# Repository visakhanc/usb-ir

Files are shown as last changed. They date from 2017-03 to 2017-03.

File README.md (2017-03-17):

USB-IR - IR receiver based on V-USB
===================================

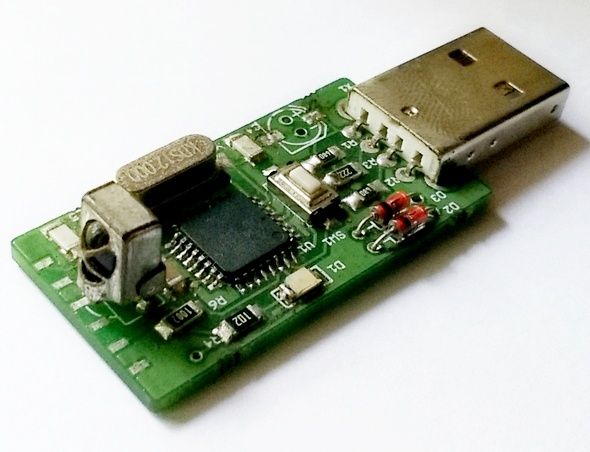
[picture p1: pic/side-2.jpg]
HID IR Remote


USB-IR is an infrared remote control receiver with a USB communication enabled by v-usb usb stack. So, it can be programmed as an IR receiver for PC with specific functions assigned to various keys of a remote control.

HID Bootloader option
---------------------

Firmware updates can be done through USB itself! For this, HID bootloader should be initially flashed into the AVR through ISP pins. After this, to program firmware using bootloader, just plug in the USB while pressing and holding the button. It will get detected as 'HIDBoot' device. Now use the command line tool for HID bootloader to program hex files. like this:
bootloadHID.exe -r main.hex

Find the HID bootloader here: [HID bootloader](https://github.com/visakhanc/vusb_projects/tree/master/bootloadHID.2012-12-08)

Examples
--------

[HID IR Remote](https://github.com/visakhanc/usb-ir/blob/master/firmware/hid-ir-remote) : Demonstrates the usage of USB-IR as a multimedia remote control receiver for PC. Sony IR protocol (SIRC) is used here. Implemented functions are: Volume Up/Down, Next, Previous, Pause, Play, Stop, Mute.

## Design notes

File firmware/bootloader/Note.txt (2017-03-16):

This is HID bootloader modified for the USB-IR hardware with PORTD:1 as boot pin
XTAL: 12 MHz (chage in makefile)
Bootloader switch: PORTD:1 (change in bootloader_config.h)

STEPS:

1. make fuse
2. make flash
3. make lock (optional)

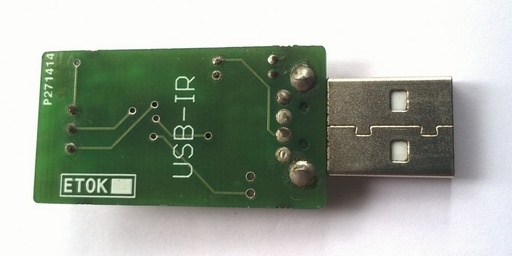
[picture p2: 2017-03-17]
pic/bottom-1.jpg

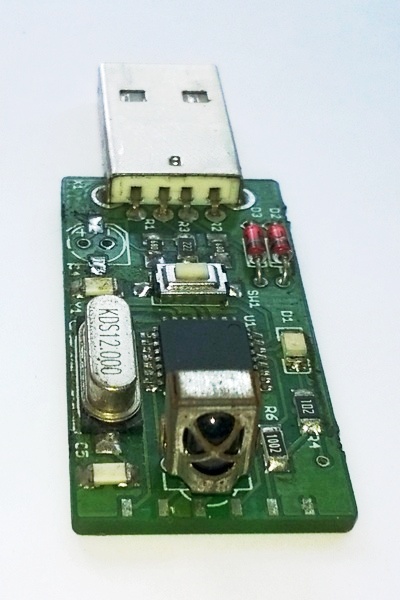
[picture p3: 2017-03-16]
pic/side-1.jpg

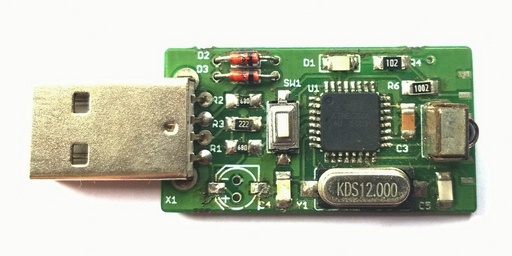
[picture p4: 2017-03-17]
pic/top-1.jpg

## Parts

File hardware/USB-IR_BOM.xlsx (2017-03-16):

Qty | Value | Device | Package | Parts | Description | Price
1 | 100n | CAP1206 | 1206 | C3 | Capacitor | 0.5
1 | 10k | RESISTOR1206 | 1206 | R6 | Resistor | 0.5
1 | 12MHz | CRYSTALSMD | HC49UP | Y1 | Various standard crystals. Proven footprints. | 12
1 | 1k | RESISTOR1206 | 1206 | R4 | Resistor | 0.5
2 | 22p | CAP1206 | 1206 | C4, C5 | Capacitor | 0.5
1 | 2k2 | RESISTOR1206 | 1206 | R3 | Resistor | 0.5
2 | 3.6V | DIODE-ZENERPTH | DIODE-ZENER | D2, D3 | Zener Diode | 2
2 | 68 | RESISTOR1206 | 1206 | R1, R2 | Resistor | 0.5
1 | CAP_POL_SMD_TH | CAP_POL_SMD_TH | CAP_SMD_TH_5X5 | C1 |  | 8
1 | MEGA8-AI | MEGA8-AI | TQFP32-08 | U1 | MICROCONTROLLER | 80
1 | RED | LED1206 | LED-1206 | D1 | LED | 2
1 | SPST_SWITCH | SPST_SWITCH | SMD_TACT_SWITCH | SW1 |  | 4
1 | USB-A-H | USB-A-H | USB-A-H | X1 | USB Connectors | 12
1 | VS1838X | VS1838X | VS1838X | U3 | VS1838 IR demodulator with supply rangeof 2.7V to 5V | 20
 |  |  |  |  | TOTAL | 146

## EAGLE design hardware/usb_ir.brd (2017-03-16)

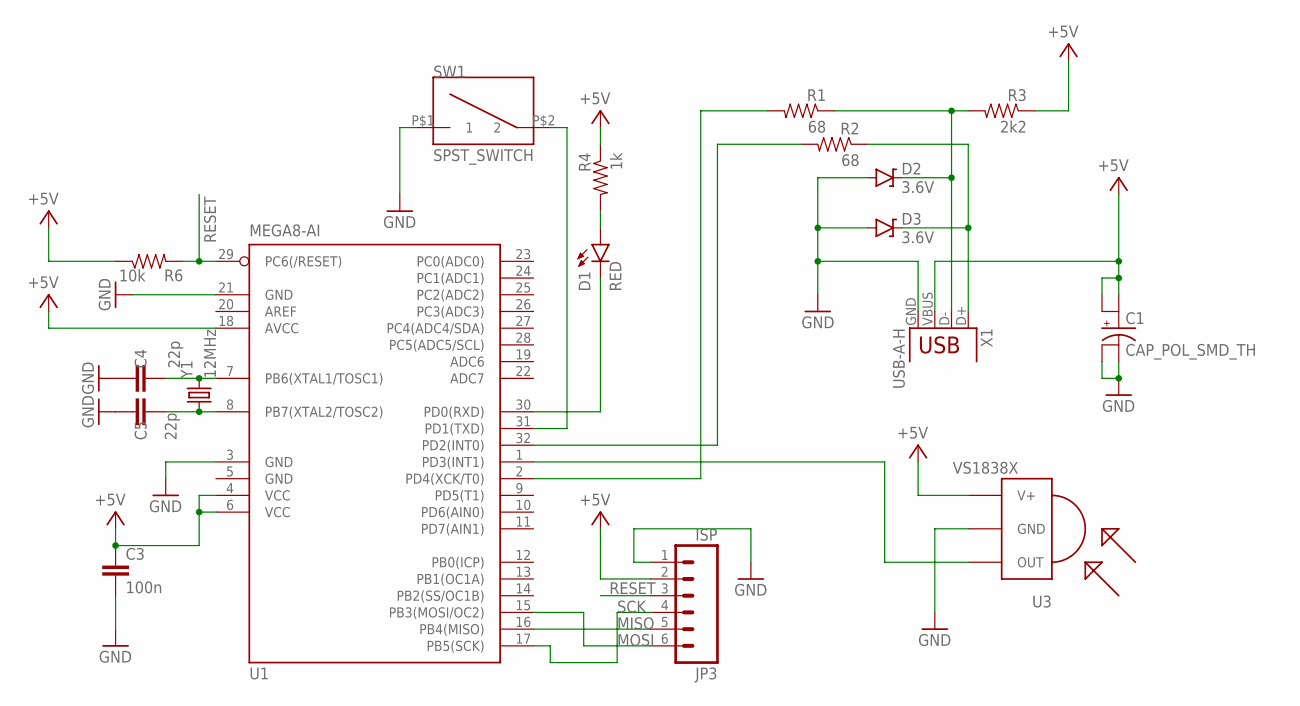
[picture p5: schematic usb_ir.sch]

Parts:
C1: CAP_POL_SMD_TH; CAP_SMD_TH_5X5
C3: 100n; 1206
C4, C5: 22p; 1206
D1: RED; LED-1206
D2, D3: 3.6V; DIODE-ZENER
JP3: ISP; 1X06-SMD_EDGE
R1, R2: 68; 1206
R3: 2k2; 1206
R4: 1k; 1206
R6: 10k; 1206
SW1: SPST_SWITCH; SMD_TACT_SWITCH
U1: MEGA8-AI; TQFP32-08
U3: VS1838X
X1: USB-A-H
Y1: 12MHz; HC49UP

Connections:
+5V: C1.+, C1.+TH (+), C3.1, JP3.2, R3.1, R4.1, R6.1, U1.4 (VCC), U1.6 (VCC), U1.18 (AVCC), U3.VCC (V+), X1.VBUS
GND: C1.-, C1.-TH (-), C3.2, C4.1, C5.1, D2.P$2 (A), D3.P$2 (A), JP3.1, SW1.P$1 (1), U1.3 (GND), U1.5 (GND), U1.21 (GND), U3.GND, X1.GND
MISO: JP3.5, U1.16 (PB4(MISO))
MOSI: JP3.6, U1.15 (PB3(MOSI/OC2))
unnamed: U1.1 (PD3(INT1)), U3.OUT
unnamed: D2.P$1 (C), R1.1, R3.2, X1.D-
unnamed: D3.P$1 (C), R2.1, X1.D+
unnamed: R2.2, U1.32 (PD2(INT0))
unnamed: R1.2, U1.2 (PD4(XCK/T0))
unnamed: D1.C, U1.30 (PD0(RXD))
unnamed: SW1.P$2 (2), U1.31 (PD1(TXD))
unnamed: D1.A, R4.2
unnamed: C4.2, U1.7 (PB6(XTAL1/TOSC1)), Y1.2
unnamed: C5.2, U1.8 (PB7(XTAL2/TOSC2)), Y1.1
RESET: JP3.3, R6.2, U1.29 (PC6(/RESET))
SCK: JP3.4, U1.17 (PB5(SCK))

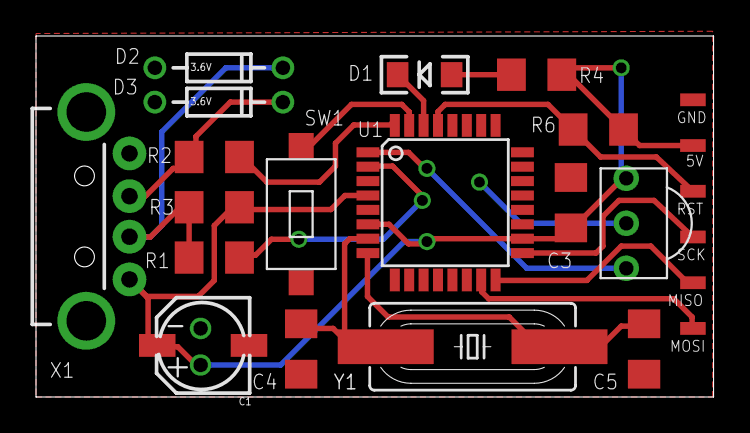
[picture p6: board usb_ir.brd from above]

Board: 2 copper layers, 37.6 x 20.1 mm, 18 parts (0 on the bottom side), 16 nets.

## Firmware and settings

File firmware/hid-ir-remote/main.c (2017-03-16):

/* Name: main.c
 * Project: hid-mouse, a very simple HID example
 * Author: Christian Starkjohann
 * Creation Date: 2008-04-07
 * Tabsize: 4
 * Copyright: (c) 2008 by OBJECTIVE DEVELOPMENT Software GmbH
 * License: GNU GPL v2 (see License.txt), GNU GPL v3 or proprietary (CommercialLicense.txt)
 */

/*
This example should run on most AVRs with only little changes. No special
hardware resources except INT0 are used. You may have to change usbconfig.h for
different I/O pins for USB. Please note that USB D+ must be the INT0 pin, or
at least be connected to INT0 as well.

We use VID/PID 0x046D/0xC00E which is taken from a Logitech mouse. Don't
publish any hardware using these IDs! This is for demonstration only!
*/

#include <avr/io.h>
#include <avr/wdt.h>
#include <avr/interrupt.h>  /* for sei() */
#include <util/delay.h>     /* for _delay_ms() */

#include <avr/pgmspace.h>   /* required by usbdrv.h */
#include "usbdrv.h"
#include "oddebug.h"        /* This is also an example for using debug macros */
#include "ir_sony.h"

#define RED_LED					PD0
#define RED_LED_DDR				DDRD
#define RED_LED_PORT			PORTD

#define RED_LED_OUT()			(RED_LED_DDR |= (1 << RED_LED))
#define RED_LED_OFF()			(RED_LED_PORT |= (1 << RED_LED))
#define RED_LED_ON()			(RED_LED_PORT &= ~(1 << RED_LED))
#define RED_LED_TOGGLE()		(RED_LED_PORT ^= (1 << RED_LED))

#define 	SEND_STATE_KB			1
#define 	SENT_STATE_KB			2
#define 	SEND_STATE_MM			3
#define 	SENT_STATE_MM			4
#define 	WAIT_STATE				0

/* Bits for Multimedia key mapping */
#define 	NO_KEYS				0
#define 	VOL_UP_KEY			(1 << 5)
#define 	VOL_DOWN_KEY		(1 << 6)
#define 	MUTE_KEY			(1 << 4)
#define 	STOP_KEY			(1 << 2)
#define 	PLAY_KEY			(1 << 3)
#define 	NEXT_KEY			(1 << 0)
#define 	PREV_KEY			(1 << 1)
#define 	POWER_KEY			(1 << 7)

/* Standard Keyboard usage codes */
#define 	KEYBOARD_RIGHT		0x4F
#define 	KEYBOARD_LEFT		0x50
#define 	KEYBOARD_UP			0x52
#define 	KEYBOARD_DOWN		0x51
#define 	KEYBOARD_F4			0x3D
#define 	KEYBOARD_ENTER		0x58
#define 	KEYBOARD_TAB		0x2B
#define 	KEYBOARD_APP		0x65
#define 	KEYBOARD_ESC		0x29
#define 	KEYBOARD_POWER		0x66

#define 	KEYBOARD_MOD_ALT	(1 << 2)
#define 	KEYBOARD_MOD_CTRL	(1 << 0)
#define 	KEYBOARD_MOD_SHIFT	(1 << 1)
#define 	KEYBOARD_MOD_GUI	(1 << 3)

/* ------------------------------------------------------------------------- */
/* ----------------------------- USB interface ----------------------------- */
/* ------------------------------------------------------------------------- */

/* Keyboard report descriptor*/
PROGMEM const char usbHidReportDescriptor[104] = { /* USB report descriptor, size must match usbconfig.h */
	
	0x05, 0x01,						// USAGE PAGE(Generic desktop)
	0x09, 0x06,						// USAGE (Keyboard)
	0xa1, 0x01,						// COllection (application)
	0x85, 0x01,						// 	  Usage ID(1)
	0x05, 0x07,                    //     USAGE_PAGE (Keycodes)
    0x19, 0xE0,                    //     USAGE_MINIMUM (224)
    0x29, 0xE7,                    //     USAGE_MAXIMUM (231)
    0x15, 0x00,                    //     LOGICAL_MINIMUM (0)
    0x25, 0x01,                    //     LOGICAL_MAXIMUM (1)
    0x95, 0x08,                    //     REPORT_COUNT (8)
    0x75, 0x01,                    //     REPORT_SIZE (1)
    0x81, 0x02,                    //     INPUT (Data,Var,Abs) ->Modifier byte
    0x95, 0x01,                    //     REPORT_COUNT (1)
    0x75, 0x08,                    //     REPORT_SIZE (8)
    0x81, 0x01,                    //     INPUT (Const) -> Reserved byte
    0x95, 0x05,                    //     REPORT_COUNT (5)
    0x75, 0x01,                    //     REPORT_SIZE (1)
	0x05, 0x08,                    //     USAGE_PAGE (LEDs)
//	0x85, 0x01,						// 		ReportID(1)
    0x19, 0x01,                    //     USAGE_MINIMUM (1)
    0x29, 0x05,                    //     USAGE_MAXIMUM (5)
	0x91, 0x02,					   //	  Output(Data, variable, Abs) -> LED report
    0x95, 0x01,						// 		REPORT_COUNT (1)
	0x75, 0x03,						//		REPORT_SIZE (3)
	0x91, 0x01,						// 		Output(Const)
	0x75, 0x08,                    //     REPORT_SIZE (8)
    0x95, 0x06,                    //     REPORT_COUNT (6)
    0x15, 0x00,						//		Logical Min(0)
	0x25, 0x65,						// 		Logical Max(101)
	0x05, 0x07,						// 		Usage Page (Keycodes)
	0x19, 0x00,						//		Usage Min(0)
	0x29, 0x65,						//		Usage Max(101)
	0x81, 0x00,                    //     INPUT (Data,Array)
    0xC0,                          // END COLLECTION

    0x05, 0x0C,                    // USAGE_PAGE (Consumer)
    0x09, 0x01,                    // USAGE (Consumer control)
    0xa1, 0x01,                    // COLLECTION (Application)
	0x85, 0x02,						// 	ReportID(2)
	0x05, 0x0C,						// USAGE_PAGE (Consumer)
    0x15, 0x00,                    //     LOGICAL_MINIMUM (0)
    0x25, 0x01,                    //     LOGICAL_MAXIMUM (1)
    0x75, 0x01,                    //     REPORT_SIZE (1)
	0x95, 0x07,                    //     REPORT_COUNT (8)
	0x09, 0xB5,						// 		NEXT TRACK (BIT 0)
	0x09, 0xB6,						// 		PREV TRACK (BIT 1)
	0x09, 0xB7,						// 		STOP (BIT 2)
	0x09, 0xCD,						//		PLAY/PAUSE(BIT 3)
	0x09, 0xE2,						// 		MUTE (BIT 4)
	0x09, 0xE9,						//		VOL INCREMENT (BIT 5)
	0x09, 0xEA,						//		VOL DECREMENT (BIT 6)
	0x81, 0x02,						// 		INPUT(Data, variable, absolute)
	0x95, 0x01,						// 	  REPORT COUNT(1)
	0x81, 0x01,						// 		INPUT(Constant)
    0xC0                          // END COLLECTION
};

/* Multimedia keys report */
typedef struct{
	uint8_t reportId;
	uint8_t key_byte;
}multi_report_t;

/* Keyboard report */
typedef struct{
	uint8_t reportId;
	uint8_t modifier;
	uint8_t _reserved;
	uint8_t keycode[6];
}keyboard_report_t;


static multi_report_t multi_report_buf = { .reportId = 2};
static keyboard_report_t keyboard_report_buf = { .reportId = 1 };
static uint8_t state = WAIT_STATE;
static uint8_t idleRate;
static uint8_t ledState;
static uint8_t bytes_remaining;
static uint8_t *send_buf;
static uint8_t ovf_count;

/* ------------------------------------------------------------------------- */
usbMsgLen_t usbFunctionSetup(uchar data[8])
{
usbRequest_t    *rq = (void *)data;

    if((rq->bmRequestType & USBRQ_TYPE_MASK) == USBRQ_TYPE_CLASS){    /* class request type */
        if(rq->bRequest == USBRQ_HID_GET_REPORT){  /* wValue: ReportType (highbyte), ReportID (lowbyte) */
            if(rq->wValue.bytes[0] == 1) { /* report id: 1 (keyboard)*/
				keyboard_report_buf.modifier = 0;
				keyboard_report_buf.keycode[0] = 0;
				usbMsgPtr = (usbMsgPtr_t)&keyboard_report_buf;
				return sizeof(keyboard_report_buf);
			}
			else if(rq->wValue.bytes[0] == 2) { /* report id: 2 (multimedia keys)*/
				multi_report_buf.key_byte = 0;
				usbMsgPtr = (usbMsgPtr_t)&multi_report_buf;
				return sizeof(multi_report_buf);
			}
        }
		else if(rq->bRequest == USBRQ_HID_SET_REPORT) {
			if(rq->wLength.word == 1) { /* set keyboard LEDs */
				return USB_NO_MSG; /* pass on to usbFunctionWrite() */
			}
		}else if(rq->bRequest == USBRQ_HID_GET_IDLE){
            usbMsgPtr = (usbMsgPtr_t)&idleRate;
            return 1;
        }else if(rq->bRequest == USBRQ_HID_SET_IDLE){
            idleRate = rq->wValue.bytes[1];
        }
    }else{
        /* no vendor specific requests implemented */
    }
    return 0;   /* default for not implemented requests: return no data back to host */
}

usbMsgLen_t	usbFunctionWrite(uint8_t *data, uint8_t len)
{
	if(ledState == data[0]) { /* same value as present */
		return 1; 
	}
	else {
		ledState = data[0];
	}

	/* LED for Capslock */
	if(ledState & 0x2) {
		RED_LED_ON();
	} 
	else {
		RED_LED_OFF();
	}

	return 1;
}
/* ------------------------------------------------------------------------- */


static void timer_init(void)
{
	TCCR1B = 0x2;
	TIMSK |= (1 << 2);
}

static void timer_reset(void)
{
	ovf_count = 0;
}



static void Get_IR(void)
{
	rc_code_t ir_code; 
	uint8_t key_byte = NO_KEYS;  /* Pressd Multimedia key */
//	uint16_t code;
	uint8_t code;
	int8_t i;
	
	if(ovf_count < 6) {
		return;
	}
	
	if(0 != rc_get(&ir_code)) {
		timer_reset();
		RED_LED_TOGGLE();
//		code = (uint16_t)((ir_code.data[2] << 8) | ir_code.data[3]);
		code = ir_code.data;
#if 0
		for(i = 15; i >= 0; i--) {
			RED_LED_ON();
			_delay_ms(50);
			RED_LED_OFF();
			_delay_ms(50);
			if(code & (1 << i)) {
				RED_LED_ON();
				_delay_ms(50);
				RED_LED_OFF();
				_delay_ms(50);
			}
			_delay_ms(500);
		}
#endif
		switch(code) {
			case RC_VOL_UP: 
				key_byte = VOL_UP_KEY;
				break;
			case RC_VOL_DOWN:
				key_byte = VOL_DOWN_KEY;
				break;
			case RC_RIGHT:
				key_byte = NEXT_KEY;
				break;
			case RC_LEFT:
				key_byte = PREV_KEY;
				break;
			case RC_POWER:
				key_byte = STOP_KEY;
				break;
			case RC_OK:
				key_byte = PLAY_KEY;
				break;
			case RC_MUTE:
				key_byte = MUTE_KEY;
				break;
#if 0
			case RC_MENU:
				keyboard_report_buf.keycode[0] = 0;
				keyboard_report_buf.modifier = KEYBOARD_MOD_GUI;
				break;
			case RC_OPTION:
				keyboard_report_buf.keycode[0] = KEYBOARD_TAB;
				break;
			case RC_INFO:
				keyboard_report_buf.keycode[0] = KEYBOARD_APP;
				break;
			case RC_RETURN:
				keyboard_report_buf.keycode[0] = KEYBOARD_ESC;
				break;
			case RC_LEFT:
				keyboard_report_buf.keycode[0] = KEYBOARD_LEFT;
				break;
			case RC_RIGHT:
				keyboard_report_buf.keycode[0] = KEYBOARD_RIGHT;
				break;
			case RC_UP:
				keyboard_report_buf.keycode[0] = KEYBOARD_UP;
				break;
			case RC_DOWN:
				keyboard_report_buf.keycode[0] = KEYBOARD_DOWN;
				break;
			case RC_OK:
				keyboard_report_buf.keycode[0] = KEYBOARD_ENTER;
				break;
			case RC_EXIT:
				keyboard_report_buf.keycode[0] = KEYBOARD_F4;
				keyboard_report_buf.modifier = KEYBOARD_MOD_ALT;
				break;
			case RC_ASPECT:
				keyboard_report_buf.keycode[0] = KEYBOARD_TAB;
				keyboard_report_buf.modifier = KEYBOARD_MOD_ALT;
#endif
			default:
				key_byte = NO_KEYS;
				break;
		}
		
		if(key_byte != NO_KEYS) {  /* Multimedia report to be sent */
			multi_report_buf.key_byte = key_byte;
			send_buf = (uint8_t *)&multi_report_buf;
			bytes_remaining = sizeof(multi_report_buf);
			state = SEND_STATE_MM;
		}
		else if(keyboard_report_buf.keycode[0] || keyboard_report_buf.modifier) { /* Keyboard report to be sent */
			send_buf = (uint8_t *)&keyboard_report_buf;
			bytes_remaining = sizeof(keyboard_report_buf);
			state = SEND_STATE_KB;
		}
	}
}

int __attribute__((noreturn)) main(void)
{
uchar   i;

    wdt_enable(WDTO_1S);
    /* Even if you don't use the watchdog, turn it off here. On newer devices,
     * the status of the watchdog (on/off, period) is PRESERVED OVER RESET!
     */
    /* RESET status: all port bits are inputs without pull-up.
     * That's the way we need D+ and D-. Therefore we don't need any
     * additional hardware initialization.
     */
    usbInit();
	rc_init();
    usbDeviceDisconnect();  /* enforce re-enumeration, do this while interrupts are disabled! */
    i = 0;
    while(--i){             /* fake USB disconnect for > 250 ms */
        wdt_reset();
        _delay_ms(1);
    }
    usbDeviceConnect();
	RED_LED_OUT();
	RED_LED_OFF();
	timer_init();
    sei();
    for(;;){                /* main event loop */
        wdt_reset();
        usbPoll();
		Get_IR();
        if(usbInterruptIsReady()){
			switch(state) {
				case SEND_STATE_MM:					
					usbSetInterrupt(send_buf, bytes_remaining);
					multi_report_buf.key_byte = NO_KEYS; /* Empty the report (no keys pressed) */
					state = SENT_STATE_MM;
					break;
				case SEND_STATE_KB:
					usbSetInterrupt((void *)send_buf, (bytes_remaining > 8)? 8 : bytes_remaining);
					if(bytes_remaining > 8) {
						send_buf += 8;
						bytes_remaining -= 8;
						state = SEND_STATE_KB;
					}
					else {
						send_buf = (uint8_t *)&keyboard_report_buf;
						bytes_remaining = sizeof(keyboard_report_buf);
						keyboard_report_buf.modifier = 0;
						keyboard_report_buf.keycode[0] = 0;
						state = SENT_STATE_KB;
					}
					break;
				case SENT_STATE_MM:
					usbSetInterrupt((void *)&multi_report_buf, sizeof(multi_report_buf));
					state = WAIT_STATE;
					break;
				case SENT_STATE_KB:
					usbSetInterrupt((void *)send_buf, (bytes_remaining > 8)? 8 : bytes_remaining);
					if(bytes_remaining > 8) {
						send_buf += 8;
						bytes_remaining -= 8;
						state = SENT_STATE_KB;
					}
					else {
						state = WAIT_STATE;
					}
					break;
				case WAIT_STATE:
				default:
					break;	
			}
		}
	
    }
}


ISR(TIMER1_OVF_vect)
{
	if(ovf_count < 0xFF) {
		ovf_count++;
	}
}
	
/* ------------------------------------------------------------------------- */

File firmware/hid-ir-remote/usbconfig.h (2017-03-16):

/* Name: usbconfig.h
 * Project: V-USB, virtual USB port for Atmel's(r) AVR(r) microcontrollers
 * Author: Christian Starkjohann
 * Creation Date: 2005-04-01
 * Tabsize: 4
 * Copyright: (c) 2005 by OBJECTIVE DEVELOPMENT Software GmbH
 * License: GNU GPL v2 (see License.txt), GNU GPL v3 or proprietary (CommercialLicense.txt)
 */

#ifndef __usbconfig_h_included__
#define __usbconfig_h_included__

/*
General Description:
This file is an example configuration (with inline documentation) for the USB
driver. It configures V-USB for USB D+ connected to Port D bit 2 (which is
also hardware interrupt 0 on many devices) and USB D- to Port D bit 4. You may
wire the lines to any other port, as long as D+ is also wired to INT0 (or any
other hardware interrupt, as long as it is the highest level interrupt, see
section at the end of this file).
*/

/* ---------------------------- Hardware Config ---------------------------- */

#define USB_CFG_IOPORTNAME      D
/* This is the port where the USB bus is connected. When you configure it to
 * "B", the registers PORTB, PINB and DDRB will be used.
 */
#define USB_CFG_DMINUS_BIT      4
/* This is the bit number in USB_CFG_IOPORT where the USB D- line is connected.
 * This may be any bit in the port.
 */
#define USB_CFG_DPLUS_BIT       2
/* This is the bit number in USB_CFG_IOPORT where the USB D+ line is connected.
 * This may be any bit in the port. Please note that D+ must also be connected
 * to interrupt pin INT0! [You can also use other interrupts, see section
 * "Optional MCU Description" below, or you can connect D- to the interrupt, as
 * it is required if you use the USB_COUNT_SOF feature. If you use D- for the
 * interrupt, the USB interrupt will also be triggered at Start-Of-Frame
 * markers every millisecond.]
 */
#define USB_CFG_CLOCK_KHZ       (F_CPU/1000)
/* Clock rate of the AVR in kHz. Legal values are 12000, 12800, 15000, 16000,
 * 16500, 18000 and 20000. The 12.8 MHz and 16.5 MHz versions of the code
 * require no crystal, they tolerate +/- 1% deviation from the nominal
 * frequency. All other rates require a precision of 2000 ppm and thus a
 * crystal!
 * Since F_CPU should be defined to your actual clock rate anyway, you should
 * not need to modify this setting.
 */
#define USB_CFG_CHECK_CRC       0
/* Define this to 1 if you want that the driver checks integrity of incoming
 * data packets (CRC checks). CRC checks cost quite a bit of code size and are
 * currently only available for 18 MHz crystal clock. You must choose
 * USB_CFG_CLOCK_KHZ = 18000 if you enable this option.
 */

/* ----------------------- Optional Hardware Config ------------------------ */

/* #define USB_CFG_PULLUP_IOPORTNAME   D */
/* If you connect the 1.5k pullup resistor from D- to a port pin instead of
 * V+, you can connect and disconnect the device from firmware by calling
 * the macros usbDeviceConnect() and usbDeviceDisconnect() (see usbdrv.h).
 * This constant defines the port on which the pullup resistor is connected.
 */
/* #define USB_CFG_PULLUP_BIT          4 */
/* This constant defines the bit number in USB_CFG_PULLUP_IOPORT (defined
 * above) where the 1.5k pullup resistor is connected. See description
 * above for details.
 */

/* --------------------------- Functional Range ---------------------------- */
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

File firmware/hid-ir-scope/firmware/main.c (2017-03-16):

/* Name: main.c
 * Project: 
 * Author: 
 * Creation Date: 
 * Tabsize: 
 */


#include <avr/io.h>
#include <avr/wdt.h>
#include <avr/interrupt.h>  /* for sei() */
#include <util/delay.h>     /* for _delay_ms() */

#include <avr/pgmspace.h>   /* required by usbdrv.h */
#include "usbdrv.h"

/* F_CPU = 12000000; For 5.33us timer clock, use 1/64 prescalar */
#define TCCR0_VAL 				0x3

/* Max number of time samples to collect */
#define MAX_SAMPLES				250

#define RED_LED					PD0
#define RED_LED_DDR				DDRD
#define RED_LED_PORT			PORTD

#define RED_LED_OUT()			(RED_LED_DDR |= (1 << RED_LED))
#define RED_LED_OFF()			(RED_LED_PORT |= (1 << RED_LED))
#define RED_LED_ON()			(RED_LED_PORT &= ~(1 << RED_LED))
#define RED_LED_TOGGLE()		(RED_LED_PORT ^= (1 << RED_LED))


/* ------------------------------------------------------------------------- */
/* ----------------------------- USB interface ----------------------------- */
/* ------------------------------------------------------------------------- */

PROGMEM const char usbHidReportDescriptor[21] = {    /* USB report descriptor */
    0x06, 0x00, 0xff,              // USAGE_PAGE (Generic Desktop)
    0x09, 0x01,                    // USAGE (Vendor Usage 1)
    0xa1, 0x01,                    // COLLECTION (Application)
    0x15, 0x00,                    //   LOGICAL_MINIMUM (0)
    0x26, 0xff, 0x00,              //   LOGICAL_MAXIMUM (255)
    0x75, 0x08,                    //   REPORT_SIZE (8)
    0x95, 0x08,                    //   REPORT_COUNT (8)
    0x09, 0x00,                    //   USAGE (Undefined)
    0x81, 0x02,              		//   INPUT (Data,Var,Abs)
    0xc0                           // END_COLLECTION
};

 
/* HID Input report structure */
typedef struct {
	uint8_t start;
	uint8_t id;
	uint16_t duration;
} report_t;


static report_t report_buf[2];
static uint8_t ledState;

volatile static uint8_t timer0_ovf;
volatile static uint8_t ovf_2;
volatile static uint8_t id;
volatile static uint8_t edge;
volatile static uint8_t idle = 1;
static uint16_t duration[MAX_SAMPLES];
static uint8_t in_ptr;
static uint8_t out_ptr;

/* ------------------------------------------------------------------------- */

usbMsgLen_t usbFunctionSetup(uchar data[8])
{
usbRequest_t    *rq = (void *)data;

    if((rq->bmRequestType & USBRQ_TYPE_MASK) == USBRQ_TYPE_CLASS){    /* class request type */
        if(rq->bRequest == USBRQ_HID_GET_REPORT){  /* wValue: ReportType (highbyte), ReportID (lowbyte) */
			usbMsgPtr = (void *)&report_buf;
			return sizeof(report_buf);
        }
		else if(rq->bRequest == USBRQ_HID_SET_REPORT) {
			return USB_NO_MSG; /* pass on to usbFunctionWrite() */
		}
    }else{
        /* no vendor specific requests implemented */
    }
    return 0;   /* default for not implemented requests: return no data back to host */
}

usbMsgLen_t	usbFunctionWrite(uint8_t *data, uint8_t len)
{
	if(ledState == data[0]) { /* same value as present */
		return 1; 
	}
	else {
		ledState = data[0];
	}
	return 1;
}
/* ------------------------------------------------------------------------- */


static void Timer0_Init(void)
{
	TIMSK |= (1 << 0);  // Enable Timer0 Overflow interrupt

	/* Start Timer0 */
	TCCR0 = TCCR0_VAL;
}

static void rc_init(void)
{
	Timer0_Init();
	
	/* External INT1 */
	MCUCR |= (1 << ISC11); /* Falling edge generates interrupt */
	MCUCR &= ~(1 << ISC10);
	GICR |= (1 << INT1); /* Enable INT1 interrupt */

	edge = 0; /* Initialiy look for falling edge */
	timer0_ovf = 0;
	idle = 1;
}




int main(void)
{
	uchar   i;

    wdt_enable(WDTO_1S);
    /* Even if you don't use the watchdog, turn it off here. On newer devices,
     * the status of the watchdog (on/off, period) is PRESERVED OVER RESET!
     */
    /* RESET status: all port bits are inputs without pull-up.
     * That's the way we need D+ and D-. Therefore we don't need any
     * additional hardware initialization.
     */
    usbInit();
	rc_init();
    usbDeviceDisconnect();  /* enforce re-enumeration, do this while interrupts are disabled! */
    i = 0;
    while(--i) {             /* fake USB disconnect for > 250 ms */
        wdt_reset();
        _delay_ms(1);
    }
    usbDeviceConnect();
	RED_LED_OUT();
	RED_LED_OFF();
    sei();
    for(;;) {                /* main event loop */
        wdt_reset();
        usbPoll();
		if(usbInterruptIsReady()) {
			report_buf[0].start = idle;
			if(out_ptr < in_ptr) {
				report_buf[0].duration = duration[out_ptr++];
				id++;
			}
			report_buf[0].id = id;
			report_buf[1].start = idle;
			if(out_ptr < in_ptr) {
				report_buf[1].duration = duration[out_ptr++];
				id++;
			}
			report_buf[1].id = id;
			usbSetInterrupt((void *)&report_buf[0], sizeof(report_buf));
		}
		if(idle == 1) {
			id = 0;
			in_ptr = 0;
			out_ptr = 0;
		}
    }
}


/* ISR for INT1 external interrupt */
ISR(INT1_vect)
{
	uint8_t count;
	int16_t dur;
	
	RED_LED_TOGGLE();
	if(!idle) {
		count = TCNT0;
		if(in_ptr < MAX_SAMPLES) {
			if((timer0_ovf > 0x80) || (ovf_2)) {
				timer0_ovf = 0x7F;
				count = 0xFF;
			}
			dur = (int16_t)((timer0_ovf << 8) + count);
			if(edge == 1) { /* This is rising edge, so store duration as negative */
				dur = -dur;
			}
			duration[in_ptr++] = dur;
		}
	}
	idle = 0;
	TCNT0 = 0;
	timer0_ovf = 0;
	ovf_2 = 0;
	if(edge == 0) {
		/* This was falling edge; next rising edge */
		MCUCR |= (1 << ISC10);
		edge = 1;
	}
	else {
		/* This was rising edge; next falling edge */
		MCUCR &= ~(1 << ISC10); 
		edge = 0;
	}
}

/* ISR for Timer0 overflow interrupt */
ISR(TIMER0_OVF_vect)
{
	timer0_ovf++;
	if(!timer0_ovf) { /* second overflow */
		ovf_2++;
		RED_LED_OFF();
	}
	
	/* Idle for ~1.5s (256 x 256 x 5.33us x 4) -> Wrap buffer to intial state
		This is the time given to send all of the buffer to USB (256 samples)
		Now capture a new sequence starting with a falling edge
	*/
	if(ovf_2 == 4) {
		idle = 1;
		edge = 0;
		MCUCR &= ~(1 << ISC10);
	}
}


/* ------------------------------------------------------------------------- */

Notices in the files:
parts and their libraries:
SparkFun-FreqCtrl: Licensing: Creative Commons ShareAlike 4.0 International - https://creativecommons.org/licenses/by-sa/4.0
